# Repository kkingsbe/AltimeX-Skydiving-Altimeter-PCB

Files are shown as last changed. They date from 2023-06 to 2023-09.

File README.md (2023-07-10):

# AltimeX

This repo contains the PCB files for an open-source ColorAlti analog that I created, which can be made for about $30. Sadly, the programmer cable costs anywhere from $60-$120, however if you need yours programmed you can reach out to me and we can work something out (I have one).

This is still an active work in progress. A LiPo with a capacity of at least 250mAh should be fine since the current draw of the board is minimal. The CAD files for an enclosure that can fit in the audible pocket on helmets will be up soon once tested.

## Bill of Materials
|Part |Part Number |Price (per item)|Amount|Link|
|---|---|---|---|----|
|MCU |STM32F103 |$6.66 |1 |[Click Here](https://www.digikey.com/en/products/detail/stmicroelectronics/STM32F103C8T6/1646338)|
|LED Strip |WS2813B |$15.00 |1 |[Click Here](https://www.amazon.com/LOAMLIN-Individually-Addressable-144Pixels-Waterproof/dp/B0BDRCQWWQ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)|
|Boost Converter |RP400N501A-TR-FE |$1.48 |1 |[Click Here](https://www.digikey.com/en/products/detail/nisshinbo-micro-devices-inc/RP400N501A-TR-FE/10244946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)|
|Linear Regulator|LD1117S33TR |$0.66 |1 |[Click Here](https://www.digikey.com/en/products/detail/stmicroelectronics/LD1117S33TR/585766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)|
|Schottky Diode  |RSX101MM-30TFTR |$0.45 |1 |[Click Here](https://www.digikey.com/en/products/detail/rohm-semiconductor/RSX101MM-30TFTR/9748173)|
|10uh Inductor |ASPI-0630LR-100M-T15 |$0.83 |1 |[Click Here](https://www.digikey.com/en/products/detail/abracon-llc/ASPI-0630LR-100M-T15/3059602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)|
|10uF Capactior  | |$0.25 |3 |[Click Here](https://www.digikey.com/en/products/detail/murata-electronics/GRM21BR61E106KA73L/2334874)|
|4.7uF Capacitor | |$0.10 |1 |[Click Here](https://www.digikey.com/en/products/detail/samsung-electro-mechanics/CL21A475KAQNNNE/3886902)|
|100nF Capacitor | |$0.10 |7 |[Click Here](https://www.digikey.com/en/products/detail/yageo/CC0805KRX7R9BB104/302874)|
|JTAG Connector  |FTSH-105-01-H-DV-K-P-TR|$5.63 |1 |[Click Here](https://www.digikey.com/en/products/detail/samtec-inc./FTSH-105-01-H-DV-K-P-TR/9594223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)|
|4.7k Resistor | |$0.10 |2 |[Click Here](https://www.digikey.com/en/products/detail/yageo/RC0402JR-074K7L/726477)|
|500 ohm Resistor| |$2.64 |1 |[Click Here](https://www.digikey.com/en/products/detail/vishay-dale/TNPU0805500RAZEN00/6615940)|
|1M Resistor | |$0.10 |1 |[Click Here](https://www.digikey.com/en/products/detail/yageo/RC0805FR-071ML/727445)|
|10MHz Resonator | |$0.24 |1 |[Click Here](https://www.digikey.com/en/products/detail/yageo/RC0805FR-071ML/727445)|
|SMD LED | |$0.26 |1 |[Click Here](https://www.digikey.com/en/products/detail/liteon/LTST-C191KRKT/386837)|
|Micro USB Port  | |$0.46 |1 |[Click Here](https://www.digikey.com/en/products/detail/amphenol-cs-fci/10118193-0001LF/2785388)|
|Baro Sensor |LPS22HBTR |$2.13 |1 |[Click Here](https://www.digikey.com/en/products/detail/stmicroelectronics/LPS22HBTR/5799910)|

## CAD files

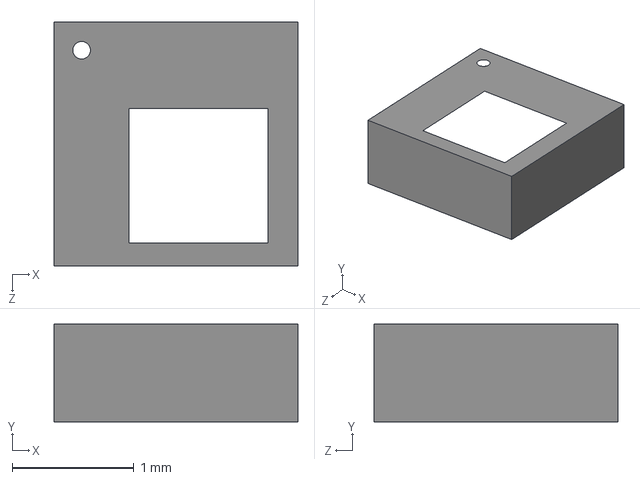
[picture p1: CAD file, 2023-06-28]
External Symbols & Footprints/LPS22HBTR Baro Sensor/LPS22HBTR.step
2.00 x 0.8 x 2.00 mm

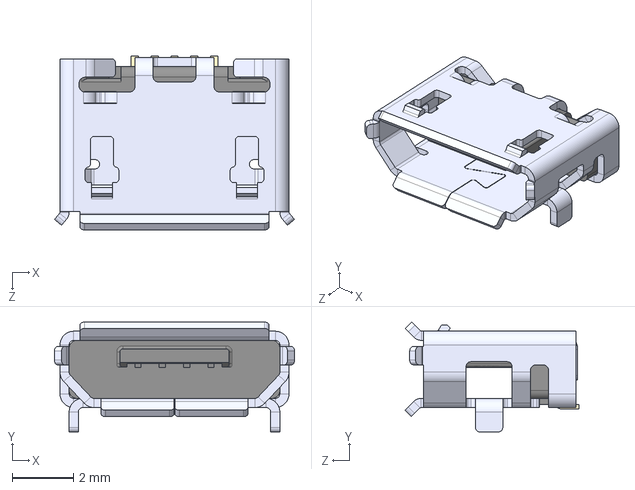
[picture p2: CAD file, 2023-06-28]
External Symbols & Footprints/Micro USB Port/10118193-0001LF.step
7.86 x 3.60 x 5.71 mm

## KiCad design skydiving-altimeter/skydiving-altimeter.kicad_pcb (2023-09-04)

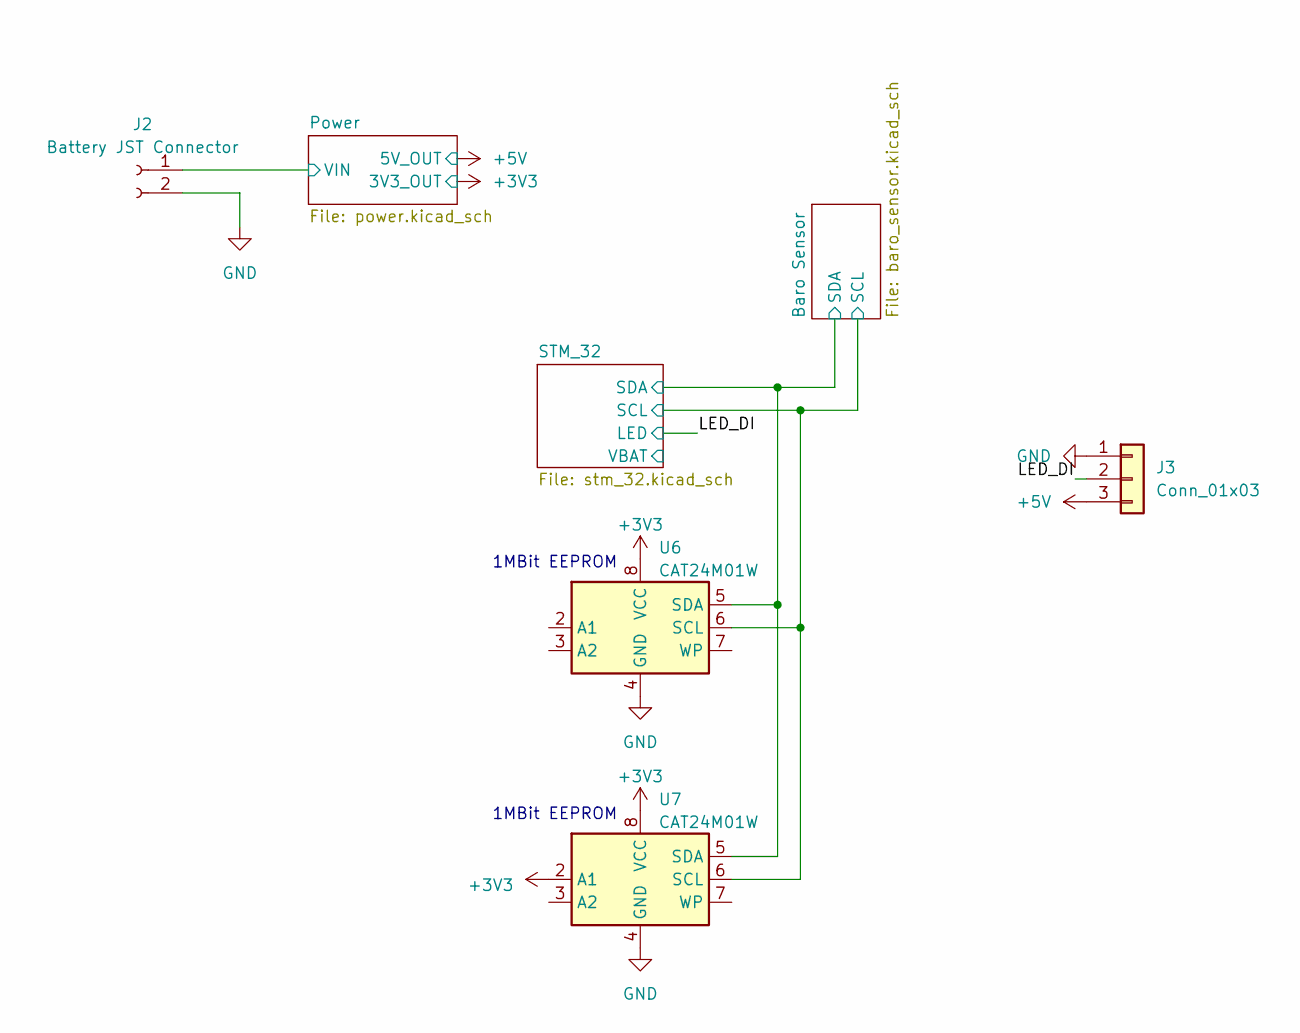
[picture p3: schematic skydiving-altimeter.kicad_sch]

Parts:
J2: Battery JST Connector; JST_S2B-PH-K-S(LF)(SN)
J3: Conn_01x03; PinHeader_1x03_P2.54mm_Vertical
U6, U7: CAT24M01W; SOIC-8_3.9x4.9mm_P1.27mm

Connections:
+3V3: U6.8 (VCC), U7.2 (A1), U7.8 (VCC); also elsewhere on the board
+5V: J3.3; also elsewhere on the board
/Baro Sensor/SCL: U6.6 (SCL), U7.6 (SCL); also elsewhere on the board
/Baro Sensor/SDA: U6.5 (SDA), U7.5 (SDA); also elsewhere on the board
/LED_DI: J3.2; also elsewhere on the board
/Power/VIN: J2.1; also elsewhere on the board
GND: J2.2, J3.1, U6.4 (GND), U7.4 (GND); also elsewhere on the board

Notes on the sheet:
1MBit EEPROM

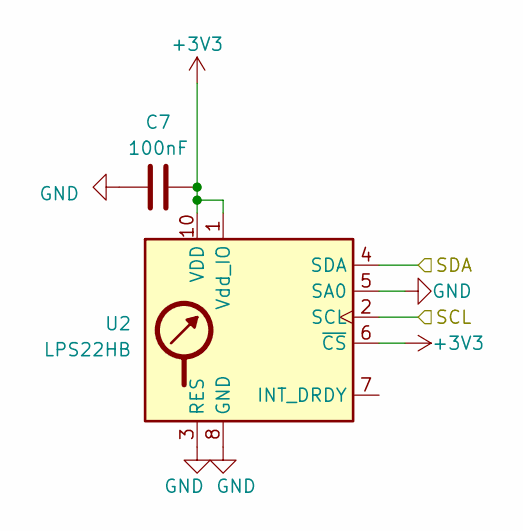
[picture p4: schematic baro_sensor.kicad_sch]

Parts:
C7: 100nF; C_0805_2012Metric
U2: LPS22HB; ST_HLGA-10_2x2mm_P0.5mm_LayoutBorder3x2y

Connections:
+3V3: C7.1, U2.1 (Vdd_IO), U2.6 (~CS), U2.10 (VDD); also elsewhere on the board
/Baro Sensor/SCL: U2.2 (SCL); also elsewhere on the board
/Baro Sensor/SDA: U2.4 (SDA); also elsewhere on the board
GND: C7.2, U2.3 (RES), U2.5 (SA0), U2.8 (GND), U2.9 (GND); also elsewhere on the board

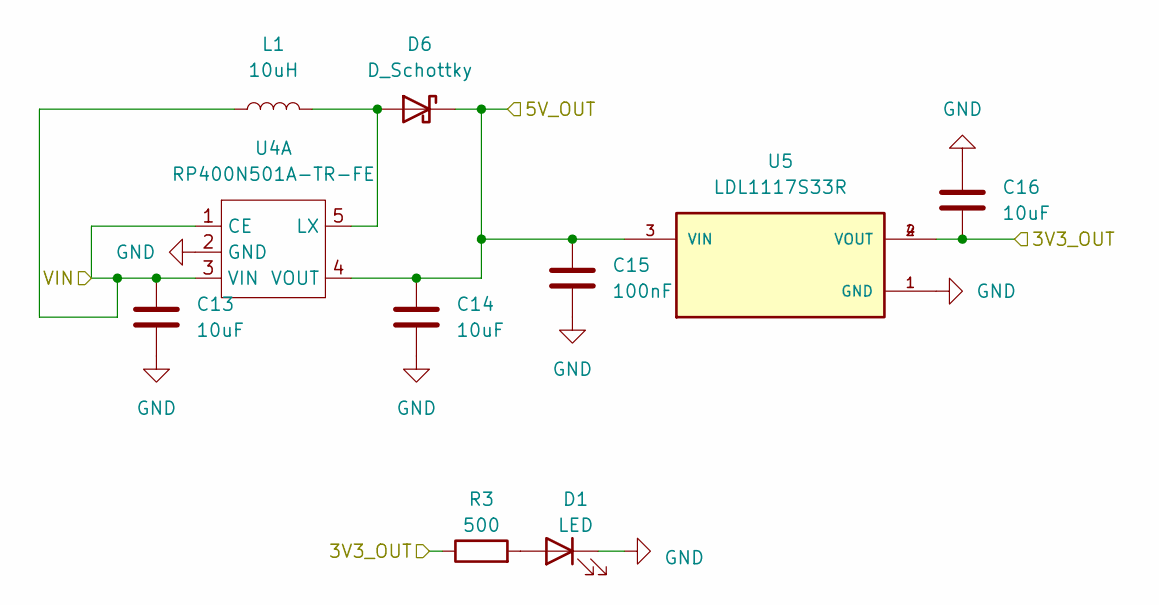
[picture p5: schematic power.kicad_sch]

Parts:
C13, C14, C16: 10uF; C_0805_2012Metric
C15: 100nF; C_0805_2012Metric
D1: LED; D_0603_1608Metric
D6: D_Schottky; D_SOD-123F
L1: 10uH; IND_ASPI-0630LR-100M-T15
R3: 500; R_0805_2012Metric
U4: RP400N501A-TR-FE; SOT-23-5
U5: LDL1117S33R; SOT-223; PARTREV 7

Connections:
+3V3: C16.2, R3.1, U5.2 (VOUT), U5.4 (VOUT); also elsewhere on the board
+5V: C14.1, C15.1, D6.1 (K), U4.4 (VOUT), U5.3 (VIN); also elsewhere on the board
/Power/VIN: C13.1, L1.1, U4.1 (CE), U4.3 (VIN); also elsewhere on the board
GND: C13.2, C14.2, C15.2, C16.1, D1.1 (K), U4.2 (GND), U5.1 (GND); also elsewhere on the board
unnamed: D1.2 (A), R3.2
unnamed: D6.2 (A), L1.2, U4.5 (LX)

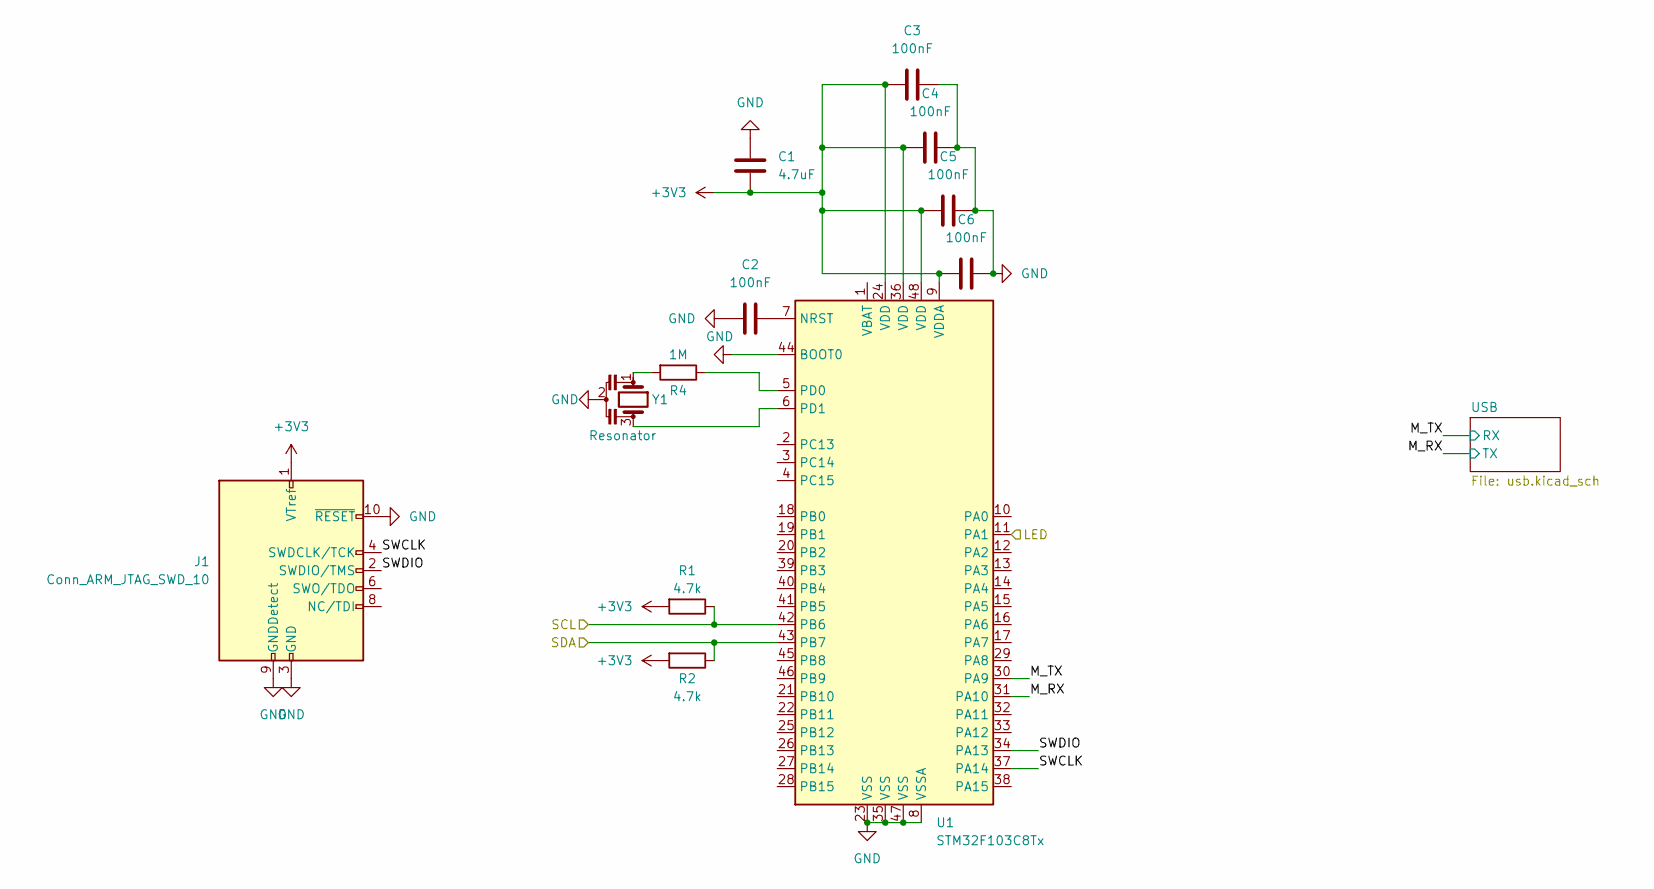
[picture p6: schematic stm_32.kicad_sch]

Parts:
C1: 4.7uF; C_0805_2012Metric
C2, C3, C4, C5, C6: 100nF; C_0805_2012Metric
J1: Conn_ARM_JTAG_SWD_10; PinHeader_2x05_P1.27mm_Vertical_SMD
R1, R2: 4.7k; R_0402_1005Metric
R4: 1M; R_0805_2012Metric
U1: STM32F103C8Tx; LQFP-48_7x7mm_P0.5mm
Y1: Resonator; JGC42-8828A_CSTNE10M0G550000R0

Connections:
+3V3: C1.2, C3.2, C4.2, C5.2, C6.2, J1.1 (VTref), R1.2, R2.2, U1.9 (VDDA), U1.24 (VDD), U1.36 (VDD), U1.48 (VDD); also elsewhere on the board
/Baro Sensor/SCL: R1.1, U1.42 (PB6); also elsewhere on the board
/Baro Sensor/SDA: R2.1, U1.43 (PB7); also elsewhere on the board
/LED_DI: U1.11 (PA1); also elsewhere on the board
/STM_32/M_RX: U1.31 (PA10); also elsewhere on the board
/STM_32/M_TX: U1.30 (PA9); also elsewhere on the board
/STM_32/SWCLK: J1.4 (SWDCLK/TCK), U1.37 (PA14)
/STM_32/SWDIO: J1.2 (SWDIO/TMS), U1.34 (PA13)
GND: C1.1, C2.2, C3.1, C4.1, C5.1, C6.1, J1.3 (GND), J1.5 (GND), J1.9 (GNDDetect), J1.10 (~RESET), U1.8 (VSSA), U1.23 (VSS), U1.35 (VSS), U1.44 (BOOT0), U1.47 (VSS), Y1.2; also elsewhere on the board
unnamed: R4.2, Y1.1
unnamed: C2.1, U1.7 (NRST)
unnamed: R4.1, U1.5 (PD0)
unnamed: U1.6 (PD1), Y1.3

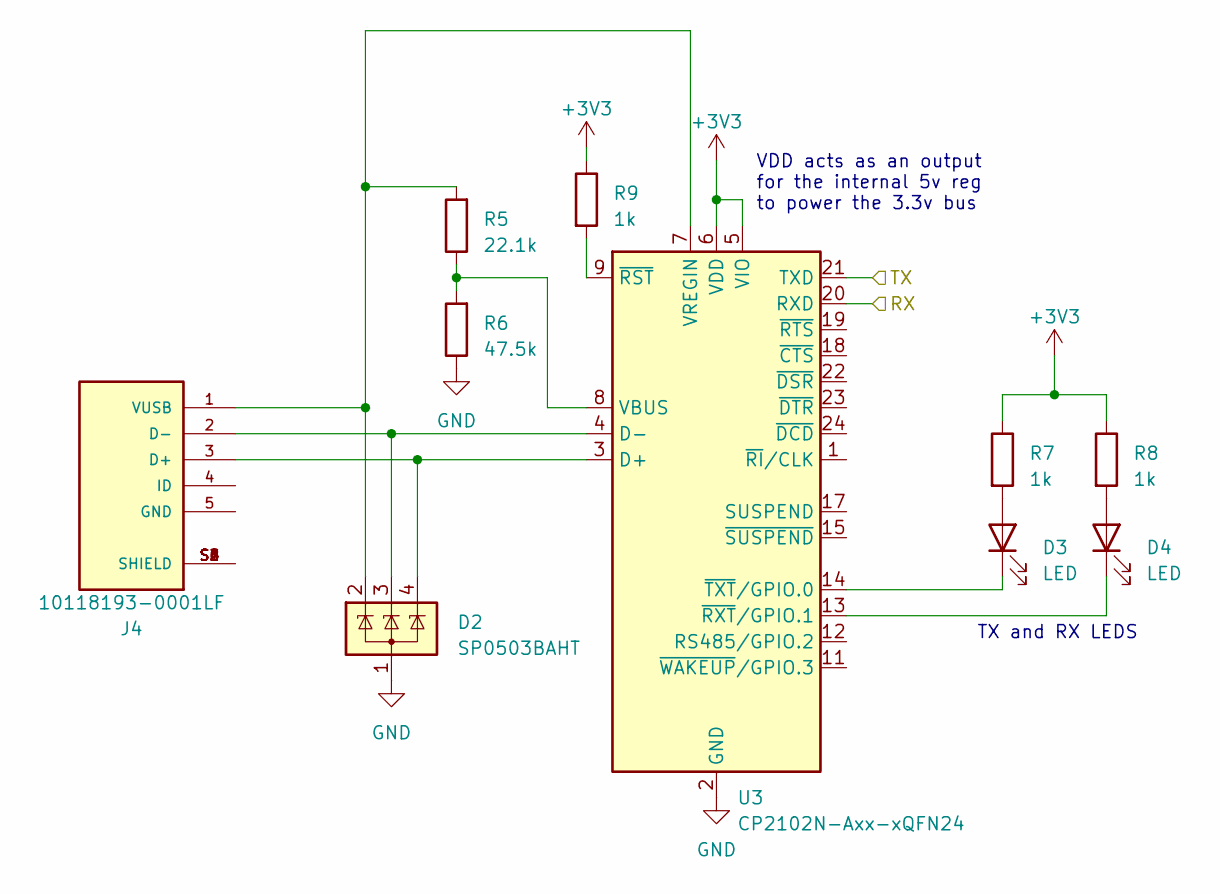
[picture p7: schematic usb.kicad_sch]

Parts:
D2: SP0503BAHT; SOT-143
D3, D4: LED; D_0603_1608Metric
J4: 10118193-0001LF; AMPHENOL_10118193-0001LF; PARTREV E
R5: 22.1k; R_0805_2012Metric
R6: 47.5k; R_0805_2012Metric
R7, R8, R9: 1k; R_0805_2012Metric
U3: CP2102N-Axx-xQFN24; QFN-24-1EP_4x4mm_P0.5mm_EP2.6x2.6mm

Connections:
+3V3: R7.1, R8.1, R9.1, U3.5 (VIO), U3.6 (VDD); also elsewhere on the board
/STM_32/M_RX: U3.21 (TXD); also elsewhere on the board
/STM_32/M_TX: U3.20 (RXD); also elsewhere on the board
GND: D2.1 (A), R6.1, U3.2 (GND), U3.25 (GND); also elsewhere on the board
unnamed: D3.2 (A), R7.2
unnamed: D3.1 (K), U3.14 (~TXT/GPIO.0)
unnamed: D4.2 (A), R8.2
unnamed: D4.1 (K), U3.13 (~RXT/GPIO.1)
unnamed 17: D2.4 (K), U3.3 (D+); also elsewhere on the board
unnamed 18: D2.3 (K), U3.4 (D-); also elsewhere on the board
unnamed 20: D2.2 (K), R5.2, U3.7 (VREGIN); also elsewhere on the board
unnamed: R5.1, R6.2, U3.8 (VBUS)
unnamed: R9.2, U3.9 (~RST)

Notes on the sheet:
TX and RX LEDS
VDD acts as an output for the internal 5v reg to power the 3.3v bus

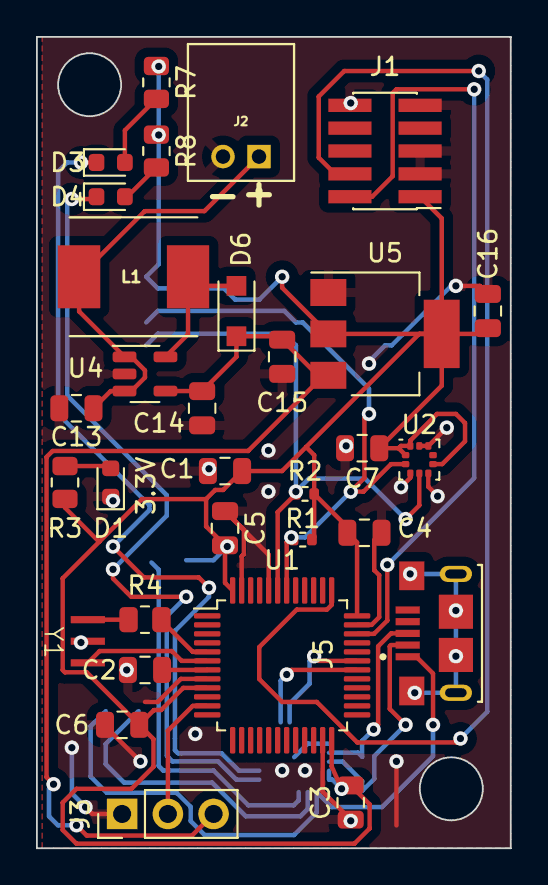
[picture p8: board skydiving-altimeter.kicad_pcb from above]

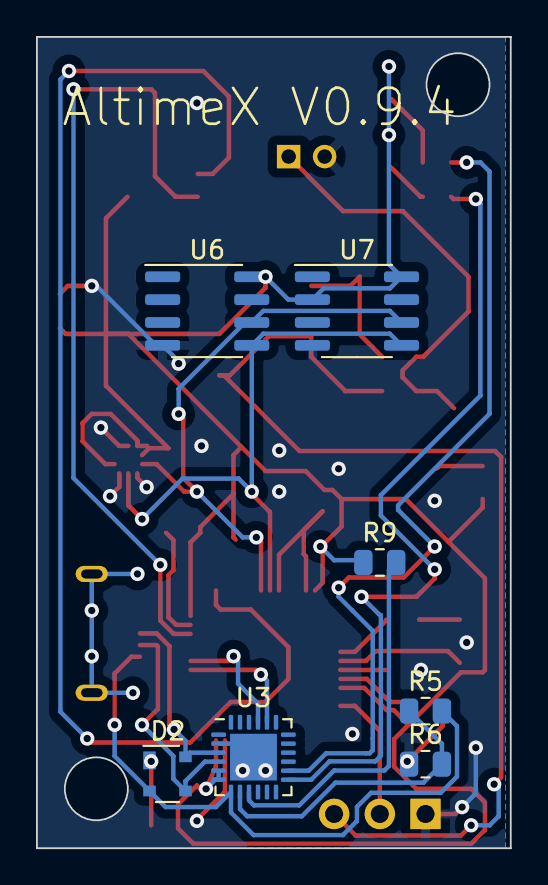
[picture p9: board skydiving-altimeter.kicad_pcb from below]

Board: 2 copper layers, 26.3 x 45.1 mm, 38 parts (7 on the bottom side), 27 nets.

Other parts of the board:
J5: 10118193-0001LF; AMPHENOL_10118193-0001LF

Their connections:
unnamed 17: J5.3 (D+); also elsewhere on the board
unnamed 18: J5.2 (D-); also elsewhere on the board
unnamed: J5.S1 (SHIELD), J5.S2 (SHIELD), J5.S3 (SHIELD), J5.S4 (SHIELD), J5.S5 (SHIELD), J5.S6 (SHIELD)
unnamed 20: J5.1 (VUSB); also elsewhere on the board

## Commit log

2023-04-17 Started rerouting
    [skydiving-altimeter.kicad_pcb, skydiving-altimeter.kicad_sch, stm_32.kicad_sch]
2023-04-18 Finished reroute
    [power.kicad_sch, skydiving-altimeter.kicad_pcb, skydiving-altimeter.kicad_sch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]
2023-04-27 First working version!
    [skydiving-altimeter-B_Cu.gbl, skydiving-altimeter-B_Mask.gbs, skydiving-altimeter-B_Paste.gbp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]
2023-06-02 Began adding 10 ohm current limiting resistors
    [baro_sensor.kicad_sch, power.kicad_sch, skydiving-altimeter.kicad_pcb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]
2023-06-02 Fixed CSB pin routing
    [baro_sensor.kicad_sch, skydiving-altimeter.kicad_pcb]
2023-06-28 Switched from the bmp to the lps. Added usb port
    [10118193-0001LF.step, LPS22HBTR.step, baro_sensor.kicad_sch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]
2023-06-29 Added external resonator to allow usb
    [skydiving-altimeter.kicad_pcb, stm_32.kicad_sch]
2023-06-30 Finalize BOM
2023-06-30 Generated gerbers. Added version number to back
    [skydiving-altimeter-B_Cu.gbl, skydiving-altimeter-B_Mask.gbs, skydiving-altimeter-B_Paste.gbp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]
2023-07-14 Mostly rerouted
    [skydiving-altimeter.kicad_pcb, skydiving-altimeter.kicad_sch, stm_32.kicad_sch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]
2023-09-04 Completed reroute
    [skydiving-altimeter-B_Cu.gbl, skydiving-altimeter-B_Mask.gbs, skydiving-altimeter-B_Paste.gbp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]
